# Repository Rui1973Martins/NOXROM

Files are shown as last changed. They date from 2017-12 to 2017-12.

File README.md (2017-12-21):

# NOXROM
 is a ZX Spectrum Cartridge compatible system, that extends the ROM size beyond 16KB

To use a NOXROM cartridge a regular cartridge interface is required to plug it in to a ZX Spectrum 48KB.

Common retro interfaces are:
- Sinclair ZX Interface 2
- RAM Turbo
- Kempston Pro

Modern tnterfaces also exist, with the same compatible Cartridge socket, like the "SPECTRA Interface" by Paul Farrows.

This is a hardware implementation of a new smart cartridge, that supports 128KB, 256KB or 512KB in Flash ROM, pageable in 16KB blocks. This is implemented using a CPLD (for control logic) and a parallel interface Flash chip from ATMEL.

NOXROM cartridge is smart, in the sense that it supports side band signaling, as a form of communication, that allows ZX software to control the internal cartridge paging register, hence allowing the use of the entire Flash chip memory, mapped into the ZX Spectrum ROM 16KB address space.

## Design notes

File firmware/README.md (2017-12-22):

# Firmware

This is sample software to run as the Cartridge Firmware, in order to demonstrate how to trigger NOXROM paging.

NOTE: Currently this software is a TEST version that is compiled as a regular TAP (ZX Spectrum tape format), that is loaded into RAM through the usual process:
   LOAD ""

A later version will run directly from ROM start address (0x0000), as a boot ROM, with correct interrupt handlers defined as needed.

# How to compile
Batch file (compile.bat) is used to compile (on windows), which current function is just to compile and attach the required ZX Spectrum BASIC loader.
To compile, Pasmo assembler needs to exist on the PATH system variable.

NOTE: It can be compiled alternatively on an Unix system, given a suitable assembler, compatible with Pasmo syntax.

Main files:
- NOXTEST.asm
	Graphical oriented Paging version

- NOXTEST-Paging.asm
	Simple text oriented Paging version

Assembly code uses Pasmo assembler syntax for asm files.

Both versions page NOXROM into defined page, and then start a "fake boot" process, i.e it setups CPU state (all it's registers) into a similar state when hardware reset is done, which includes as final step, a jump to boot address 0x0000.

Note: Memory is not changed in anyway during a "fake boot".

For "fake boot" to actualy boot the machine, NOXROM must have in it's Flash memory, in the correct page (16KB slot) the required contents to boot the computer.

Flash can contain a cartridge ROM, an application or game ROM, or even a set of Pages to keep a full snapshot 48JB (3x16KB). Although the set of pages is not supported yet.

WARNING:
No actual ROM software is supplied, since many of them are copyrighted.
There are however, some that are available, like "The GOSH WONDERFUL ZX Spectrum ROM", as a compatible replacement for the ZX Spectrum 48KB ROM.

# Other uses
A large pageable Flash ROM, allows to do a lot more than just replace the ZX Spectrum internal ROM .
New software utilities or games can use the extra space available in several ways.
- To load more then 48KB of software, in a 48KB machine, by paging the Flash ROM in similar way to how the ZX Spectrum 128KB did to its 4 memory pages. The difference is that Flash ROM as a single page area to manage (the ROM one).
- To load Levels from Flash
- To "page in" Sprites or Game data required, for render.
- to "page in" Reference tables or memory aligned tables required for some speed optimization.
- etc ...

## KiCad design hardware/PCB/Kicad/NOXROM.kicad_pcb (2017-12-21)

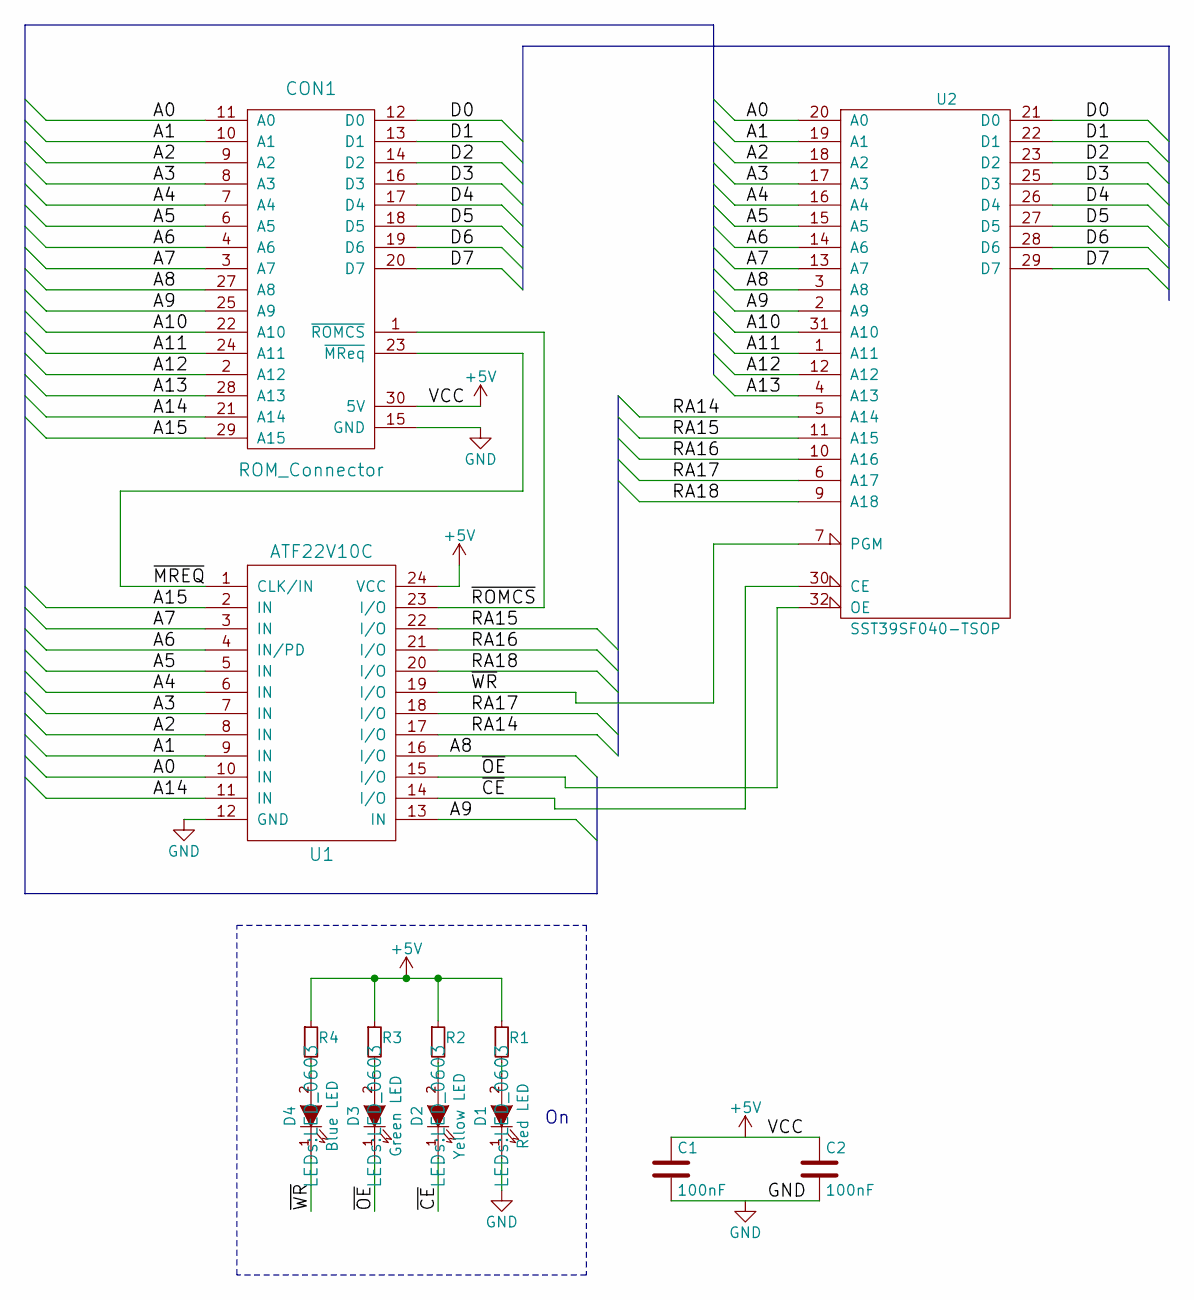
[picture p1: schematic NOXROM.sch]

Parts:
C1, C2: 100nF; C_0603
CON1: ROM_Connector; ZX_IF2_ROM_Edge_Connector
D1: Red LED; LED_0603
D2: Yellow LED; LED_0603
D3: Green LED; LED_0603
D4: Blue LED; LED_0603
R1, R2, R3, R4: R_Small; R_0603
U1: ATF22V10C; TSSOP-24_4.4x7.8mm_Pitch0.65mm
U2: SST39SF040-TSOP

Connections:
+5V: C1.1, C2.1, CON1.30 (5V), R1.1, R2.1, R3.1, R4.1, U1.24 (VCC), U2.8 (VCC)
/A0: CON1.11 (A0), U1.10 (IN), U2.20 (A0)
/A1: CON1.10 (A1), U1.9 (IN), U2.19 (A1)
/A2: CON1.9 (A2), U1.8 (IN), U2.18 (A2)
/A3: CON1.8 (A3), U1.7 (IN), U2.17 (A3)
/A4: CON1.7 (A4), U1.6 (IN), U2.16 (A4)
/A5: CON1.6 (A5), U1.5 (IN), U2.15 (A5)
/A6: CON1.4 (A6), U1.4 (IN/PD), U2.14 (A6)
/A7: CON1.3 (A7), U1.3 (IN), U2.13 (A7)
/A8: CON1.27 (A8), U1.16 (I/O), U2.3 (A8)
/A9: CON1.25 (A9), U1.13 (IN), U2.2 (A9)
/A10: CON1.22 (A10), U2.31 (A10)
/A11: CON1.24 (A11), U2.1 (A11)
/A12: CON1.2 (A12), U2.12 (A12)
/A13: CON1.28 (A13), U2.4 (A13)
/A14: CON1.21 (A14), U1.11 (IN)
/A15: CON1.29 (A15), U1.2 (IN)
/D0: CON1.12 (D0), U2.21 (D0)
/D1: CON1.13 (D1), U2.22 (D1)
/D2: CON1.14 (D2), U2.23 (D2)
/D3: CON1.16 (D3), U2.25 (D3)
/D4: CON1.17 (D4), U2.26 (D4)
/D5: CON1.18 (D5), U2.27 (D5)
/D6: CON1.19 (D6), U2.28 (D6)
/D7: CON1.20 (D7), U2.29 (D7)
/RA14: U1.17 (I/O), U2.5 (A14)
/RA15: U1.22 (I/O), U2.11 (A15)
/RA16: U1.21 (I/O), U2.10 (A16)
/RA17: U1.18 (I/O), U2.6 (A17)
/RA18: U1.20 (I/O), U2.9 (A18)
/~CE: D2.1 (K), U1.14 (I/O), U2.30 (CE)
/~MREQ: CON1.23 (~MReq), U1.1 (CLK/IN)
/~OE: D3.1 (K), U1.15 (I/O), U2.32 (OE)
/~ROMCS: CON1.1 (~ROMCS), U1.23 (I/O)
/~WR: D4.1 (K), U1.19 (I/O), U2.7 (PGM)
GND: C1.2, C2.2, CON1.15 (GND), D1.1 (K), U1.12 (GND), U2.24 (GND)
unnamed: D1.2 (A), R1.2
unnamed: D2.2 (A), R2.2
unnamed: D3.2 (A), R3.2
unnamed: D4.2 (A), R4.2

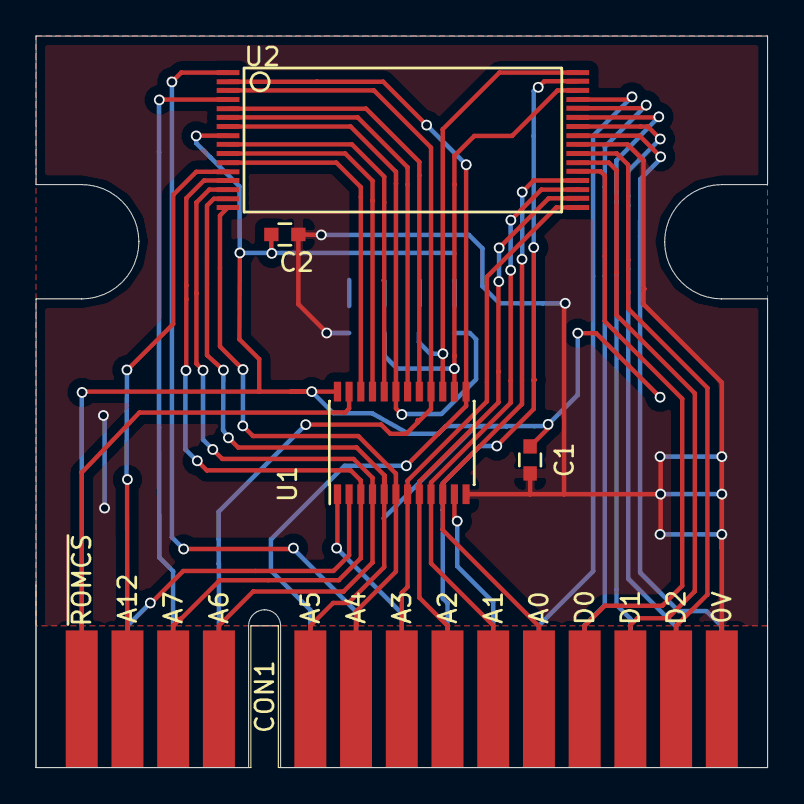
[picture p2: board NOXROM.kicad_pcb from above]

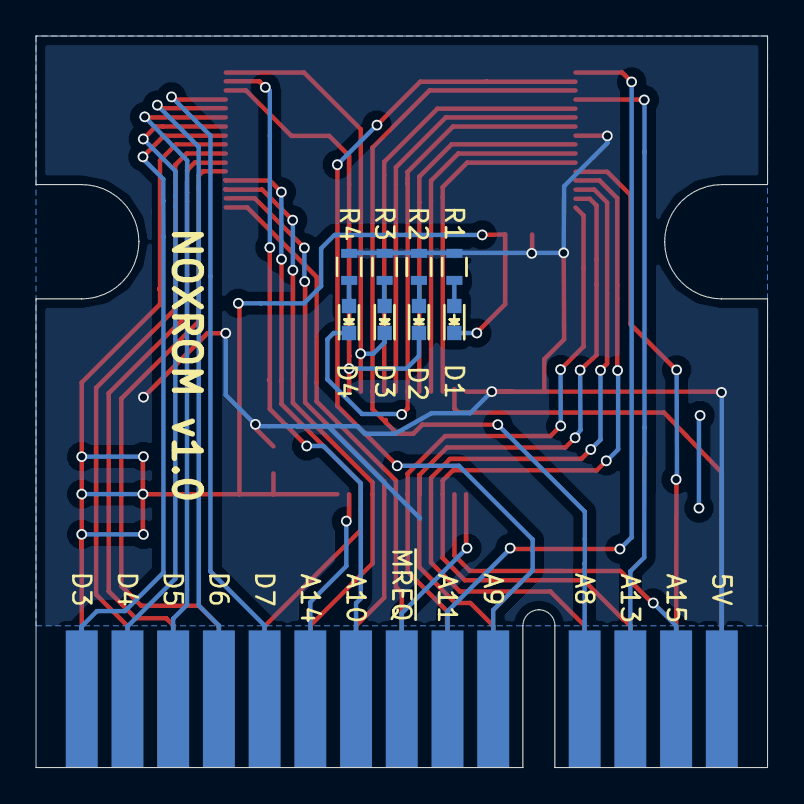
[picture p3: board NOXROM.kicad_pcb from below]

Board: 2 copper layers, 40.6 x 40.6 mm, 13 parts (8 on the bottom side), 40 nets.

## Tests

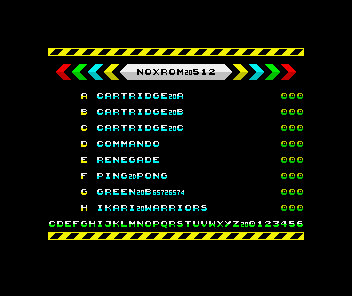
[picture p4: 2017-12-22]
firmware/TestFirmware-0.54.png

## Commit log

2017-12-21 Version 1.0
    [NOXROM-B_Cu.gbr, NOXROM-B_Mask.gbr, NOXROM-B_SilkS.gbr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]
2017-12-22 Add TestFirmware sample screenshot
